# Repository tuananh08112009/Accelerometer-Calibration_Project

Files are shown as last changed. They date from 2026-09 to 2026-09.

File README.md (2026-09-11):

# accelerometer-calibration

Calibrating an MPU-9250/6500/9255 accelerometer against known references,
in two phases:

**Phase 1 — static.** Six-position calibration using gravity as the
reference. Determines scale factor and zero offset for each axis.

**Phase 2 — dynamic.** A Scotch yoke shake table producing sinusoidal
motion of known amplitude and frequency. Determines frequency response.

## Why

This project came out of [ccs-seismicity-screener](https://github.com/Quinn-777/ccs-seismicity-screener),
a geological screening framework for induced seismicity risk at carbon
storage sites. That framework is validated against monitoring records
from three real projects — and it assumes those records are trustworthy
without ever examining how they were produced.

## Status

- [x] Sensor wired and communicating (I2C 0x68)
- [ ] Calibration cube printed
- [ ] Six-position static calibration
- [ ] Shake table built
- [ ] Frequency sweep

## Project developed by:
- Founder: Quinn Qhao (Quinn-777)
- Co-Founder: Tuan Anh Luong (tuananh08112009)

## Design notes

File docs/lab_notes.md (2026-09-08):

# Lab notes

## 2026-09-06

Wired GY-521 to Mega 2560 (VCC→5V, GND→GND, SCL→21, SDA→20).
I2C scan found the device at 0x68 first try.

Serial output was garbage at first — monitor was at 9600 baud, sketch
uses 115200. Fixed by changing the monitor.

read_raw working. Flat, chip up: ax −300, ay 40, az 7990.
Inverted: az −8120.

Datasheet says 8192 counts per g at ±4g, so the sensor reads about
2% low. That's what the calibration is for.

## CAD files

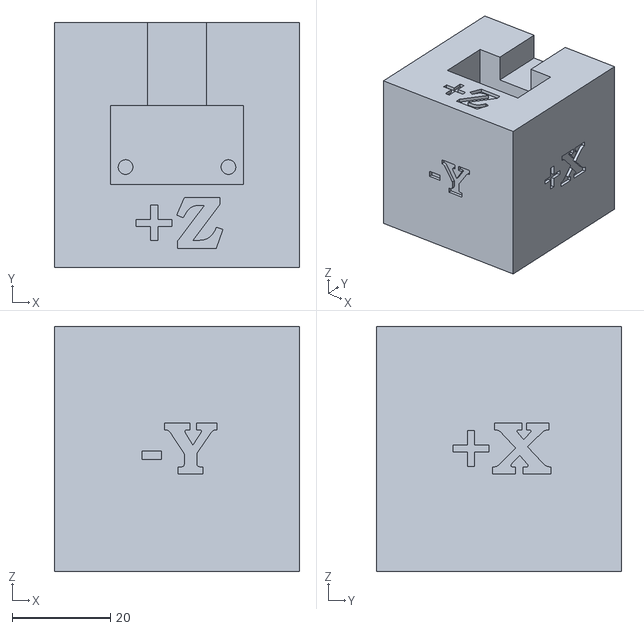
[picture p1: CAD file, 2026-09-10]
hardware/calibration_cube.stl
50.0 x 50.0 x 50.0

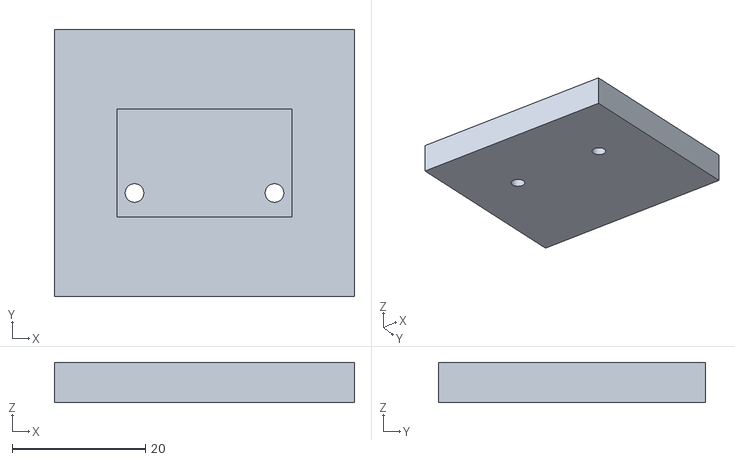
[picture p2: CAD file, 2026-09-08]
hardware/fit_test.stl
45.0 x 40.0 x 6.00

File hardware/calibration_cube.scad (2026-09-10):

// calibration_cube.scad
// Six-position calibration cube for an MPU-9250/6500/9255 breakout.
// Each face is engraved with the cube axis its outward normal points along.

// ===== COPY THESE FROM YOUR VERIFIED fit_test.scad =====
board_x   = 26.0;    // long edge of the PCB
board_y   = 15.0;    // short edge
hole_dx   = 10.5;    // hole centre, distance from board centre along X
hole_dy   = 4.5;     // hole centre, distance from board centre along Y
fit       = 0.6;     // clearance around the board, per side
hole_dia  = 3.0;     // M3 self-taps into PLA
// =======================================================

cube_size    = 50;
well_depth   = 30;   // swallows the pin header plus dupont housings
hole_depth   = 8;
channel_w    = 12;   // wire exit slot
channel_h    = 8;

label_size   = 11;   // engraved text height
label_depth  = 1.0;  // engraving depth

$fn = 48;

module face_label(txt) {
    linear_extrude(height = label_depth * 2, center = true)
        text(txt, size = label_size, halign = "center", valign = "center",
             font = "Liberation Sans:style=Bold");
}

difference() {
    cube([cube_size, cube_size, cube_size], center = true);

    // sensor well, opening on the +Z face
    translate([0, 0, cube_size/2 - well_depth/2 + 0.01])
        cube([board_x + 2*fit, board_y + 2*fit, well_depth], center = true);

    // two blind self-tapping holes in the well floor
    for (s = [-1, 1])
        translate([s * hole_dx, -hole_dy,
                   cube_size/2 - well_depth - hole_depth/2 + 0.01])
            cylinder(h = hole_depth, d = hole_dia, center = true);

    // wire exit channel through the +Y wall, open at the top edge
    translate([0, cube_size/4, cube_size/2 - channel_h/2 + 0.01])
        cube([channel_w, cube_size/2 + 0.02, channel_h], center = true);

    // ---- engraved face labels ----
    // +Z sits off-centre to clear the well and the wire channel
    translate([0, -16, cube_size/2])                face_label("+Z");
    translate([0, 0, -cube_size/2]) rotate([180,0,0])   face_label("-Z");
    translate([cube_size/2, 0, 0])  rotate([90,0,90])   face_label("+X");
    translate([-cube_size/2, 0, 0]) rotate([90,0,-90])  face_label("-X");
    translate([0, cube_size/2, 0])  rotate([90,0,180])  face_label("+Y");
    translate([0, -cube_size/2, 0]) rotate([90,0,0])    face_label("-Y");
}

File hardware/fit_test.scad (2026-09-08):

// fit_test.scad
// Fit test for an MPU-9250/6500/9255 breakout (GY-9250 style board).
// Both mounting holes sit along one edge, near the two ends.

// ===== MEASURE THESE ON YOUR OWN BOARD =====
board_x   = 25.0;    // long edge
board_y   = 15.0;    // short edge
hole_dx   = 10.5;    // hole centre, distance from board centre along X
hole_dy   = 4.5;     // hole centre, distance from board centre along Y
                     // negative side; both holes share this offset
// ===========================================

fit       = 0.6;     // clearance around the board, per side
hole_dia  = 2.8;     // M3 self-taps into PLA
plate_x   = 45;
plate_y   = 40;
plate_z   = 6;
pocket_z  = 3;

$fn = 48;

difference() {
    cube([plate_x, plate_y, plate_z], center = true);

    // pocket matching the board outline
    translate([0, 0, plate_z/2 - pocket_z/2 + 0.01])
        cube([board_x + 2*fit, board_y + 2*fit, pocket_z], center = true);

    // two holes along the same edge
    for (s = [-1, 1])
        translate([s * hole_dx, -hole_dy, 0])
            cylinder(h = plate_z * 2, d = hole_dia, center = true);
}

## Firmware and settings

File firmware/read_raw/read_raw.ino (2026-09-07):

// read_raw.ino
// Continuously prints raw accelerometer counts on all three axes.
// Tilt the board and watch the numbers change.
 
#include <Wire.h>
 
const uint8_t MPU_ADDR       = 0x68;
const uint8_t REG_PWR_MGMT   = 0x6B;
const uint8_t REG_CONFIG     = 0x1A;
const uint8_t REG_ACCEL_CFG  = 0x1C;
const uint8_t REG_ACCEL_XOUT = 0x3B;
 
void writeRegister(uint8_t reg, uint8_t value) {
  Wire.beginTransmission(MPU_ADDR);
  Wire.write(reg);
  Wire.write(value);
  Wire.endTransmission();
}
 
void setup() {
  Serial.begin(115200);
  Wire.begin();
  Wire.setClock(400000);
 
  writeRegister(REG_PWR_MGMT,  0x00);   // wake the chip up
  writeRegister(REG_CONFIG,    0x03);   // digital low pass filter, 44 Hz
  writeRegister(REG_ACCEL_CFG, 0x08);   // AFS_SEL = 1, range +/-4g
 
  Serial.println("ax\tay\taz");
}
 
void loop() {
  Wire.beginTransmission(MPU_ADDR);
  Wire.write(REG_ACCEL_XOUT);
  Wire.endTransmission(false);
  Wire.requestFrom((int)MPU_ADDR, 6, true);
 
  int16_t ax = (Wire.read() << 8) | Wire.read();
  int16_t ay = (Wire.read() << 8) | Wire.read();
  int16_t az = (Wire.read() << 8) | Wire.read();
 
  Serial.print(ax); Serial.print('\t');
  Serial.print(ay); Serial.print('\t');
  Serial.println(az);
 
  delay(200);
}

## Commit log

2026-09-08 Revise README for accelerometer calibration project
    Updated project title and added detailed calibration phases and project background.
2026-09-10 Update calibration cube for MPU-9250 with labels
    [calibration_cube.scad]
2026-09-10 change the edge and the way it look
    [calibration_cube.scad, calibration_cube.stl]
